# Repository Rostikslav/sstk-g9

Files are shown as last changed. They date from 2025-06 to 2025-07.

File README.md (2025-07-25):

# EcoSwitch

Dieses Repository enthält das Projekt im Rahmen des Moduls **Soft Skills und technische Kompetenz** an der Carl von Ossietzky Universität Oldenburg.

## 📌 Gruppe 9

**Teilnehmer:innen:**
- Vlada Kryvtsova (vlkkvl)
- Emelie Lyhs (LuciaDC245)
- Rostyslav Petrenko (Rostikslav)
- Maximilian Schmidt (DerTafel)
- Zinedin Zerarka (Shuvi12345)

## 📁 Struktur

- `app/` – Android-Applikation
- `embedded/` – Hardware und Mikrocontroller-Firmware
- `docs/` – Projektbezogene Dokumentation

## 📝 Projektbeschreibung
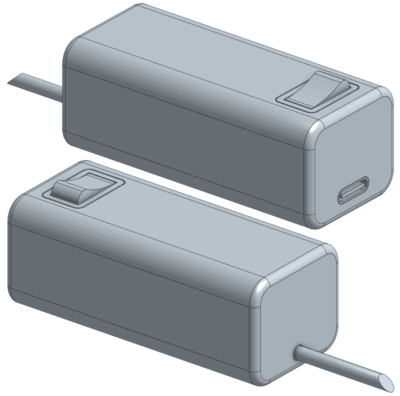
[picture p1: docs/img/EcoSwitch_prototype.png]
EcoSwitch


Ursprünglich war geplant, eine vollwertige, fernsteuerbare Steckdosenleiste zu entwickeln, mit der sich Geräte über WLAN kontrollieren lassen. Diese Idee wurde jedoch aus sicherheitstechnischen Gründen abgelehnt, da sie mit Netzspannung gearbeitet hätte und dadurch ein erhöhtes Risiko bestand.

Stattdessen wurde das Konzept angepasst: Unser aktuelles Projekt, der EcoSwitch, verfolgt dieselben Ziele – nämlich Energieeinsparung und intelligentes Gerätemanagement – aber in Form eines kompakten USB-basierten Adapters. Diese Lösung reduziert das Gefahrenpotenzial erheblich, behält aber alle geplanten Funktionen bei.

Der EcoSwitch ermöglicht:
- Fernsteuerung über eine Android-App (WLAN)
- Timer-gesteuertes Ein-/Ausschalten von angeschlossenen Geräten
- Lokale Steuerung per Taster
- LED-Statusanzeige für den aktuellen Zustand

Das Projekt zielt darauf ab, unnötigen Stromverbrauch zu reduzieren, die Lebensdauer von Geräten zu verlängern und einen kleinen, aber effektiven Beitrag zum Umweltschutz zu leisten.

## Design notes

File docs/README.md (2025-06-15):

## Docs
This directory contains project-related documentation, including planning notes, deadlines, user stories, images and other supporting materials that guide the development process and track progress.

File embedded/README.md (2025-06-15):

## Embedded
Contains all hardware- and firmware-related components of the project, including microcontroller code and circuit schematics.

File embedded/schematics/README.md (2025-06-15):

## Schematics
Includes hardware schematics, wiring diagrams, and other design files that describe the physical circuit setup used in the project.

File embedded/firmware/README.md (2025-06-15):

## Firmware
Stores the source code for the microcontroller (e.g., Arduino/ESP8266). This includes sensor handling, communication logic, and device behavior.

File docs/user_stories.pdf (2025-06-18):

EcoSwitch Projekt | User Stories

Timer-Funktionen

User Story

Als Benutzer möchte ich einen Timer fur meine Ger ¨ | äte einstellen können,
so dass ich Energie sparen und unnötigen Stromverbrauch uber Nacht vermeiden kann. ¨

Akzeptanzkriterien:

- Der Benutzer kann Timer zwischen 1 Minute und 24 Stunden einstellen
- Die Timer-Einstellung erfolgt uber eine intuitive Zeitauswahl (Stunden/Minuten) ¨
- Nach Ablauf des Timers wird das EcoSwitch automatisch ausgeschaltet
- Der Benutzer erhält eine Bestätigung, wenn der Timer erfolgreich gesetzt wurde
- Bei Verbindungsfehlern wird eine Fehlermeldung angezeigt
- Der Timer kann nur bei eingeschaltetem EcoSwitch gestartet werden

User Story

Als Benutzer möchte ich den Timer während des Betriebs anpassen können, so dass ich flexibel auf veränderte Bedurfnisse reagieren kann. ¨

Akzeptanzkriterien:

- Der aktive Timer kann verlängert oder verkurzt werden ¨
- Anderungen werden sofort an das EcoSwitch ¨ | ubertragen ¨
- Der Benutzer kann den Timer komplett stoppen/deaktivieren
- Bei Timer-Anderungen wird die neue Restzeit sofort angezeigt ¨
- Timer können nicht auf negative Werte gesetzt werden
- Eine Bestätigung erscheint bei erfolgreicher Timer-Anpassung

Fernsteuerung & Status

User Story

Als Benutzer möchte ich mein EcoSwitch-Gerät aus der Ferne ein- und ausschalten können,
so dass ich bequem vom Sofa aus Geräte steuern kann, ohne aufstehen zu mussen. ¨

Akzeptanzkriterien:

- Ein-/Ausschalten funktioniert uber einen gut sichtbaren Button in der App ¨
- Die Statusänderung wird innerhalb von 2 Sekunden ubertragen ¨
- Bei Verbindungsproblemen wird eine Fehlermeldung angezeigt

- Die erfolgreiche Verbindung wird durch eine erfolgreiche Meldung angezeigt
- Der physische Notschalter am EcoSwitch hat Vorrang vor App-Befehlen
- Befehle werden nur bei bestehender Verbindung zum EcoSwitch gesendet

User Story

Als Benutzer möchte ich den aktuellen Status meines Geräts (ein/aus/Timer aktiv) auf einen Blick sehen,
so dass ich immer weiß, ob meine Geräte gerade Strom verbrauchen.

Akzeptanzkriterien:

- Der Status wird prominent auf dem Hauptbildschirm angezeigt
- Unterschiedliche Farben fur verschiedene Zust ¨ | ände (Grun=ein, Rot=aus, Orange=Timer) ¨
- Status wird automatisch alle 5 Sekunden aktualisiert
- Status-Icons sind selbsterklärend und entsprechen der Hardware-LED
- Temperaturstatus wird zusätzlich angezeigt (Normal/Warnung/Kritisch)

User Story

Als Benutzer möchte ich eine Live-Anzeige der verbleibenden Timer-Zeit sehen, so dass ich weiß, wann mein Gerät automatisch ausgeschaltet wird.

Akzeptanzkriterien:

- Timer-Countdown wird in Echtzeit (sekundlich) aktualisiert ¨
- Zeit wird im Format “HH:MM:SS” angezeigt
- Bei inaktivem Timer wird “Kein Timer aktiv” angezeigt
- In den letzten 60 Sekunden wird die Anzeige hervorgehoben
- Bei Timer-Ablauf erscheint eine deutliche Benachrichtigung

Sicherheit & Uberwachung ¨

User Story

Als Benutzer möchte ich Temperatur-Warnungen erhalten,
so dass ich rechtzeitig uber ¨ | Uberhitzung informiert werde und Sch ¨ | äden verhindern kann.

Akzeptanzkriterien:

- Warnung bei Temperaturen uber 60 ¨ | °C (konfigurierbar)
- Kritische Warnung bei Temperaturen uber 80 ¨ | °C
- Automatische Abschaltung bei kritischen Temperaturen (uber 85 ¨ | °C)
- Temperatur wird kontinuierlich alle 10 Sekunden uberpr ¨ | uft ¨

Benutzerfreundlichkeit

User Story

Als Benutzer möchte ich eine einfache und intuitive Bedienoberfläche haben, so dass ich die App ohne Einarbeitung sofort nutzen kann.

Akzeptanzkriterien:

- Alle wichtigen Funktionen sind mit maximal 2 Klicks erreichbar
- Buttons haben aussagekräftige Beschriftungen oder universelle Icons
- Die App folgt den Android Material Design Guidelines
- Schriftgrößen sind fur alle Altersgruppen gut lesbar ¨
- Farbkontraste erfullen Accessibility-Standards ¨
- Fehlermeldungen sind verständlich

## Definition of Done (DoD)

Eine User Story gilt als fertig (Done), wenn alle folgenden Kriterien erfullt sind: ¨

Funktionale Kriterien

¥ Alle Akzeptanzkriterien der User Story sind implementiert

¥ Feature funktioniert auf Android 8.0+

¥ WiFi-Verbindung zum EcoSwitch funktioniert stabil

Technische Qualität

¥ Code ist von dem ganzen Team reviewed

¥ Integration Tests fur Hardware-Kommunikation existieren ¨

User Experience

¥ UI folgt Material Design Guidelines 3

¥ App funktioniert im Hoch- und Querformat

¥ Fehlermeldungen sind benutzerfreundlich formuliert

¥ Loading States und Progress Indicators sind implementiert

Sicherheit & Stabilität

¥ Keine sensitive Daten werden im Plain Text gespeichert

¥ App sturzt nicht ab bei Verbindungsfehlern ¨

¥ Timeout-Handling fur alle Netzwerk-Requests ¨

Testing & Dokumentation

¥ Automatisierte UI-Tests fur kritische User Flows ¨

¥ Code ist ausreichend kommentiert

¥ README enthält Build- und Setup-Anweisungen

¥ Known Issues sind dokumentiert

Performance

¥ App-Größe unter 20 MB

¥ Netzwerk-Requests unter 2 Sekunden Response Zeit

¥ UI reagiert flussig (60 FPS, keine ANRs) ¨

¥ Batterieverbauch im normalen Bereich

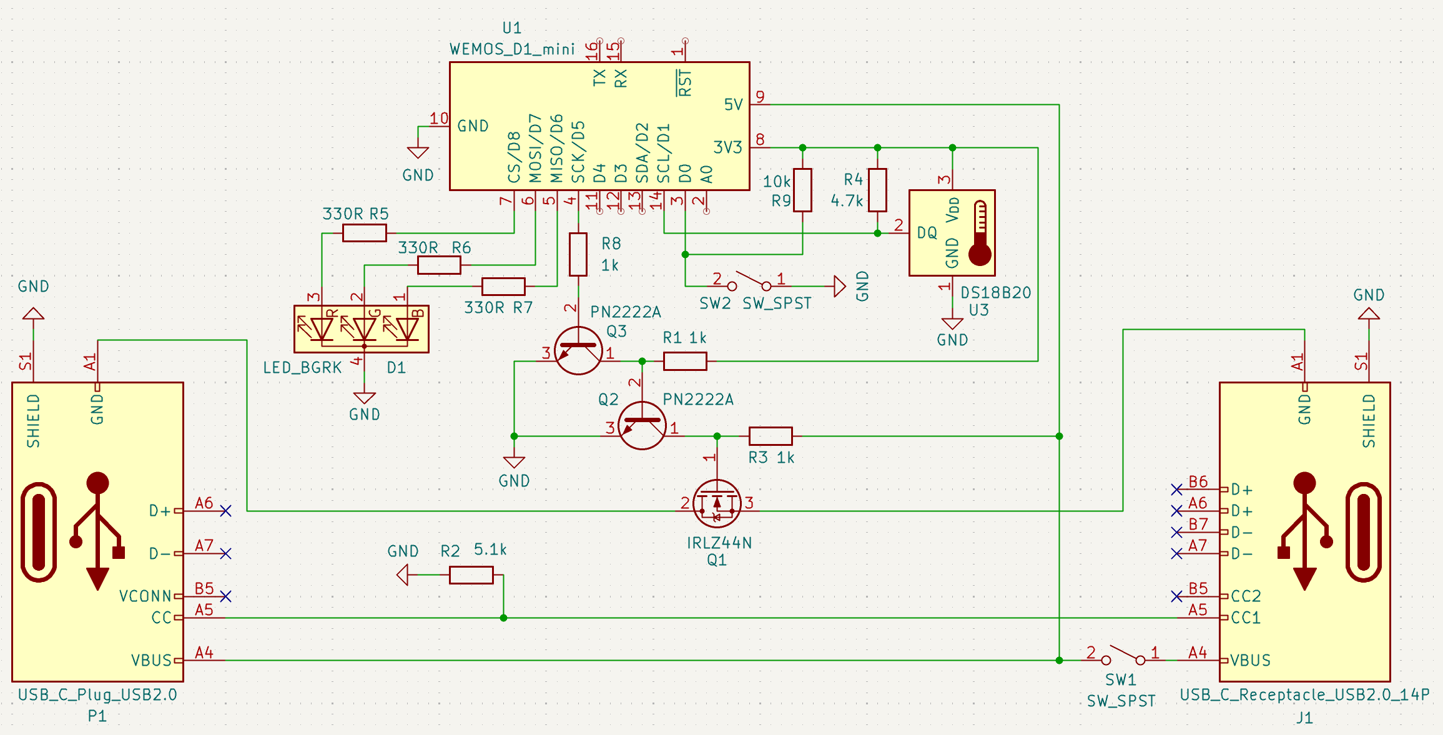
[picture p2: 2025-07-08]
embedded/schematics/schematics_final.png

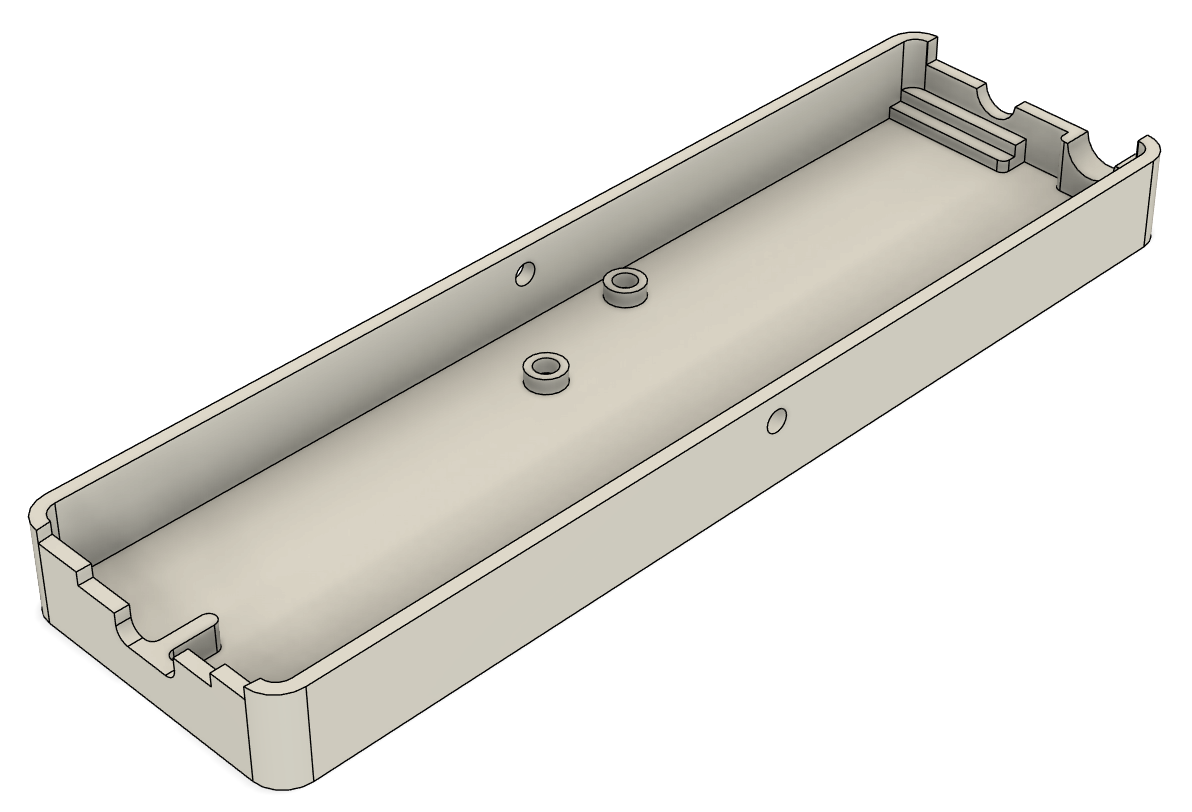
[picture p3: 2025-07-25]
docs/img/final/EcoSwitch_bottom_part_left.png

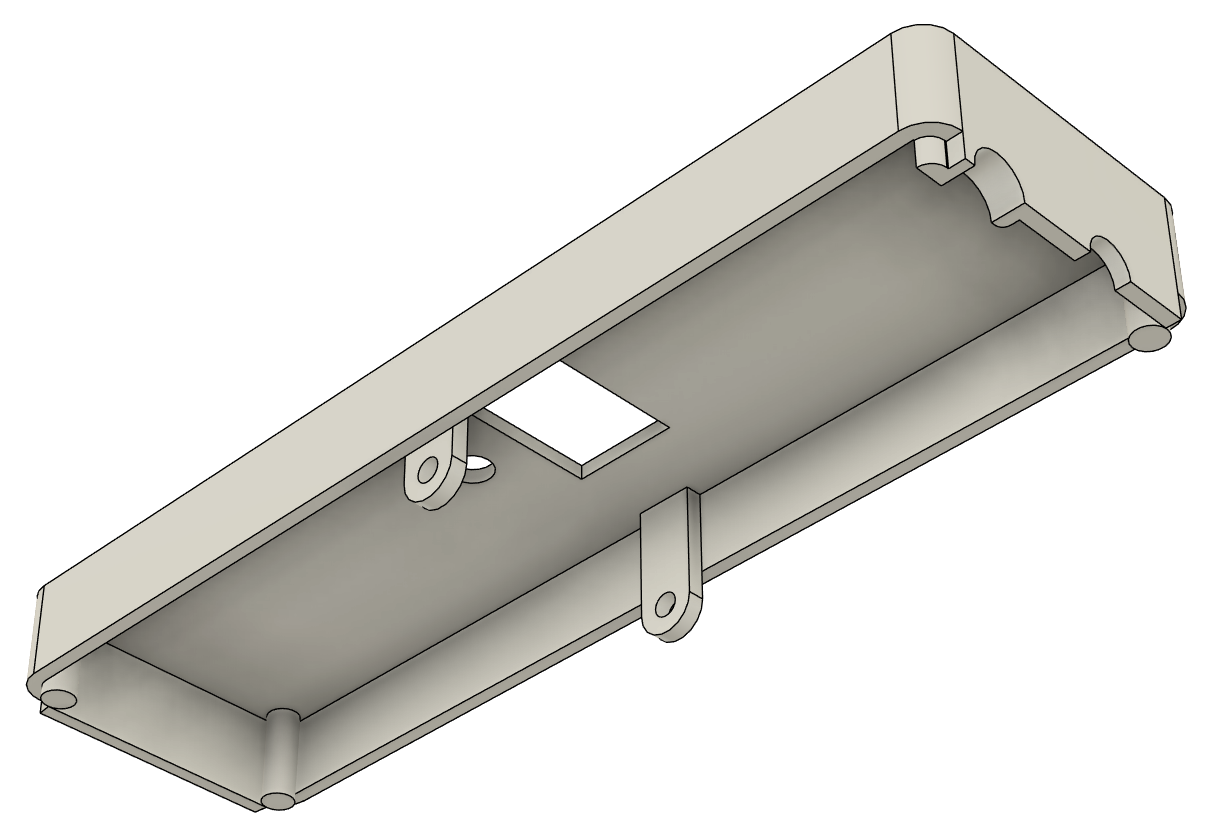
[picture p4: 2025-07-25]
docs/img/final/EcoSwitch_top_part_right.png

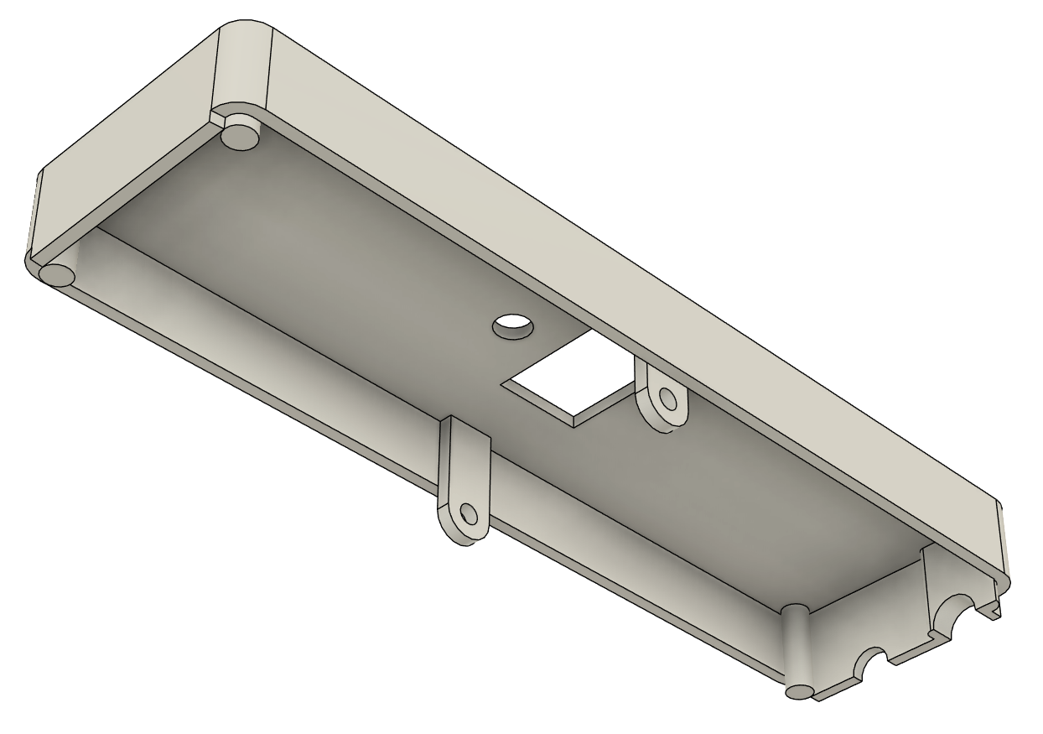
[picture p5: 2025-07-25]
docs/img/final/EcoSwitch_top_part_left.png

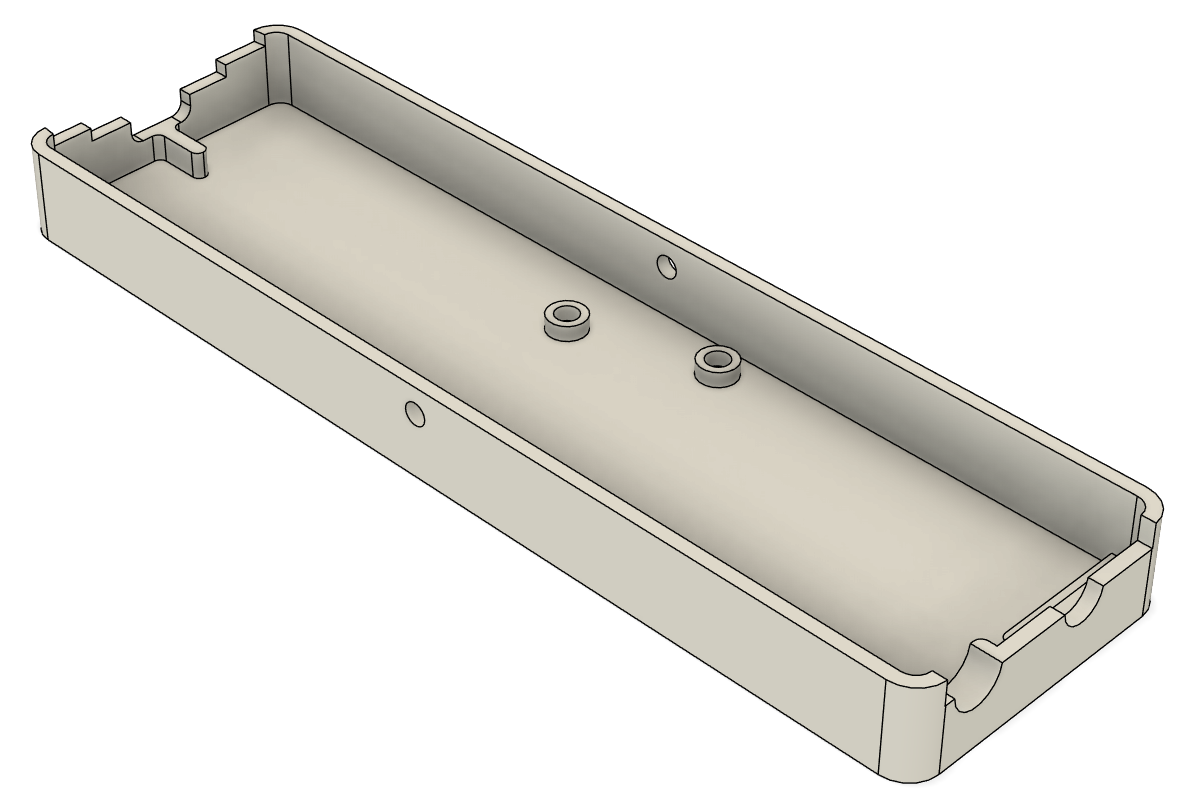
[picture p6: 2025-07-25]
docs/img/final/EcoSwitch_bottom_part_right.png

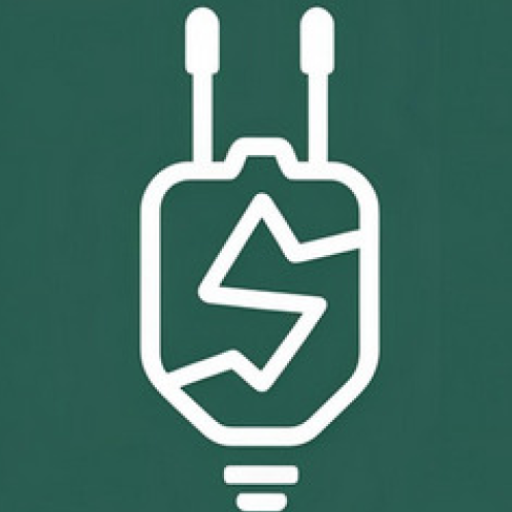
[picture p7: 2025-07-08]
app/src/main/ic_launcher-playstore.png

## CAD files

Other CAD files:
embedded/model/EcoSwitch_final.f3d

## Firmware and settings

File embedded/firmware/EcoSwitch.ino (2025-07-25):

#include <ESP8266WebServer.h>
#include <ESP8266WiFi.h>
#include <WiFiManager.h>
#include <WiFiUdp.h>
#include <EEPROM.h>
#include <Ticker.h>
#include <Wire.h>
#include <Adafruit_BMP085.h>

#include "token.h"
#include "udp.h"

#define SWITCH_PIN D5  // main control pin
#define RESET_PIN D0   // to GND on boot for reset

// indicators
#define BLUE D6
#define RED D7
#define GREEN D8

// UDP
#define BROADCAST_INTERVAL 1000    // 1sec
#define BROADCAST_DURATION 120000  // 2min

// temp sensor
#define TEMP_CUTOFF 50.0
#define TEMP_FAULTY_READING_THRESHOLD 100.0
#define TEMP_READ_INTERVAL 2000  // 2sec
#define COOLDOWN_DURATION 60000  // 1min

ESP8266WebServer server(80);
Ticker blinker;

// udp broadcast
unsigned long broadcastStart = 0;
unsigned long lastBroadcast = 0;
bool enableBroadcast = false;

unsigned long timerEnd = 0;
int timerAction = 0;

Adafruit_BMP085 bmp;
unsigned long temperatureLastRead = 0;
unsigned long cooldownEnd = 0;
bool cooldownMode = false;

// ------ LED ------

void toggle(uint8_t pin) {
    digitalWrite(pin, !digitalRead(pin));
}

void updateLedState() { // based on the switch state
    if (digitalRead(SWITCH_PIN)) {
        digitalWrite(RED, LOW);
        digitalWrite(GREEN, HIGH);
        digitalWrite(BLUE, LOW);
    } else {
        digitalWrite(RED, HIGH);
        digitalWrite(GREEN, LOW);
        digitalWrite(BLUE, LOW);
    }
}

// ------ HANDLERS ------

// validates token
bool auth() {
    if (!server.hasArg("token") || server.arg("token") != String(savedToken)) {
        server.send(403, "text/plain", "Forbidden");
        return false;
    }
    return true;
}

// check the sensor availability
bool checkSensor() {
    if (!bmp.begin()) {
        server.send(500, "text/plain", "Temperature sensor is not detected");
        return false;
    }
    return true;
}

// check whether the server is running
void handlePing() {
    server.send(200, "text/plain", "pong");
}

// initial pairing with token generation
void handleSetup() {
    if (tokenExists()) {
        server.send(403, "text/plain", "Already configured");
        return;
    }

    String token = generateToken(TOKEN_LENGTH);
    saveToken(token);
    enableBroadcast = false;
    updateLedState();
    server.send(200, "text/plain", token);
}

// getter fot the switch state(requires auth)
void handleState() {
    if (!auth())
        return;

    int remainingSeconds = timerEnd ? (timerEnd - millis()) / 1000 : 0;

    String json = "{";
    json += "\"sensorError\":" + String(!bmp.begin() ? "true" : "false") + ",";
    json += "\"state\":" + String(digitalRead(SWITCH_PIN) ? "true" : "false") + ",";
    json += "\"timerEnd\":" + String(remainingSeconds) + ",";
    json += "\"cooldownMode\":" + String(cooldownMode ? "true" : "false");
    json += "}";

    server.send(200, "application/json", json);
}

// setter for the switch state(requires auth)
void handleToggleState() {
    if (!auth() || !checkSensor())
        return;

    if (!server.hasArg("state")) {
        server.send(400, "text/plain", "Missing 'state' parameter");
        return;
    }

    String state = server.arg("state");
    if (state == "1") {
        if (cooldownMode) {
            server.send(409, "text/plain", "Device is in cooldown mode");
            return;
        }
        digitalWrite(SWITCH_PIN, HIGH);
        server.send(200, "text/plain", "ON");
    } else if (state == "0") { // allow turning off even in cooldown mode
        digitalWrite(SWITCH_PIN, LOW);
        server.send(200, "text/plain", "OFF");
    } else {
        server.send(400, "text/plain", "Invalid state. Use 1 or 0.");
    }

    updateLedState();
}

// set/reset timer
void handleTimer() {
    if (!auth() || !checkSensor())
        return;

    if (cooldownMode) {
        server.send(409, "text/plain", "Device is in cooldown mode");
        return;
    }

    if (!server.hasArg("seconds")) {
        server.send(400, "text/plain", "Missing 'seconds' parameter");
        return;
    }

    String rawSeconds = server.arg("seconds");
    int seconds = rawSeconds.toInt();
    bool isValid = rawSeconds.length() > 0 && seconds != 0;

    if (!isValid && rawSeconds != "0") {
        server.send(400, "text/plain", "Invalid parameter 'seconds'. The Value should be an integer.");
        return;
    }

    if (seconds == 0) {
        timerEnd = 0;
        server.send(200, "text/plain", "Timer deactivated.");
        return;
    }

    if (!server.hasArg("action")) {
        server.send(400, "text/plain", "Missing 'action' parameter");
        return;
    }

    String rawAction = server.arg("action");
    if (rawAction != "1" && rawAction != "0") {
        server.send(400, "text/plain", "Invalid parameter 'action'. Use 1 or 0.");
        return;
    }

    timerEnd = millis() + (unsigned long)seconds * 1000;
    timerAction = rawAction.toInt();
    server.send(200, "text/plain", "Timer set.");
}

// getter fot the temperature readings(requires auth)
void handleTemperature() {
    if (!auth() || !checkSensor())
        return;

    float temp = bmp.readTemperature();
    if (isnan(temp) || temp > TEMP_FAULTY_READING_THRESHOLD) {
        server.send(500, "text/plain", "Faulty sensor readings");
    } else {
        server.send(200, "text/plain", String(temp, 1));
    }
}

// forget connected device and reboot
void handleDisconnect() {
    if (!auth())
        return;

    clearToken();
    server.send(200, "text/plain", "Successfully disconnected");
    delay(1000);
    ESP.restart();
}

void setup() {
    pinMode(SWITCH_PIN, OUTPUT);
    pinMode(RESET_PIN, INPUT);

    pinMode(RED, OUTPUT);
    pinMode(GREEN, OUTPUT);
    pinMode(BLUE, OUTPUT);

    digitalWrite(SWITCH_PIN, LOW);
    digitalWrite(RED, LOW);
    digitalWrite(GREEN, LOW);
    digitalWrite(BLUE, LOW);

    Serial.begin(115200);
    Serial.print('\n');

    while (!bmp.begin()) { // blink red if couldn't connect to the sensor
        toggle(RED);
        delay(300);
    }
    digitalWrite(RED, LOW);

    blinker.attach(0.3, []() { // blink blue while in setup mode
        toggle(BLUE);
    });

    randomSeed(micros());
    EEPROM.begin(TOKEN_LENGTH);

    WiFiManager wm;
    if (digitalRead(RESET_PIN) == 0) { // if reset held on boot
        Serial.println("Resetting WiFi and token...");
        wm.resetSettings(); // forget network
        clearToken(); // forget paired device
        ESP.restart();
    } else {
        Serial.println("No reset");
    }

    if (!wm.autoConnect("EcoSwitch-Setup")) // try to auto-connect or open hotspot
        ESP.restart();

    loadToken();
    if (!tokenExists()) {  // only start broadcasting if no token saved
        enableBroadcast = true;
        broadcastStart = millis();
        digitalWrite(BLUE, HIGH);
    } else {
        updateLedState();
    }

    blinker.detach();
    udp.begin(UDP_PORT); // udp setup

    // server handlers
    server.on("/ping", handlePing);
    server.on("/setup", handleSetup);
    server.on("/status", handleState);
    server.on("/temperature", handleTemperature);
    server.on("/toggle", handleToggleState);
    server.on("/timer", handleTimer);
    server.on("/disconnect", handleDisconnect);
    server.begin();
}

void loop() {
    server.handleClient();
    if (!bmp.begin()) { // if sensor failure detected
        digitalWrite(SWITCH_PIN, LOW); // turn off the switch
        updateLedState();
        while (!bmp.begin()) { // while sensor offline
            server.handleClient(); // do not block incoming requests
            toggle(RED); // blink red
            delay(300);
        }
        updateLedState();
    }

    // udp broadcast condition
    if (enableBroadcast && millis() - broadcastStart < BROADCAST_DURATION && millis() - lastBroadcast > BROADCAST_INTERVAL) {
        sendIPBroadcast();
        lastBroadcast = millis();
    }

    // timer state condition
    if (timerEnd && timerEnd < millis()) {
        timerEnd = 0;
        digitalWrite(SWITCH_PIN, timerAction ? HIGH : LOW);
        updateLedState();
    }

    // temperature reading condition
    if (millis() - temperatureLastRead > TEMP_READ_INTERVAL) {
        temperatureLastRead = millis();
        if (!bmp.begin())
            return;
        float t = bmp.readTemperature();
        Serial.println(t);

        if (!isnan(t) && t >= TEMP_CUTOFF) { // if temperature too high
            digitalWrite(SWITCH_PIN, LOW); // cut the power
            updateLedState();
            cooldownMode = true; // enter cooldown mode
            timerEnd = 0; // deactivate timer
            cooldownEnd = millis() + COOLDOWN_DURATION; // set cooldown end time
        }
    }

    // cooldown exit condition
    if (cooldownEnd && millis() > cooldownEnd) {
        cooldownEnd = 0;
        cooldownMode = false;
    }
}

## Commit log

2025-06-18 add core system: - Wi-Fi connection - request auth - UDP discovery - direct switch control - delayed switch control (timer) - temp check
2025-06-21 replace temperature sensor and fix bugs
    [EcoSwitch.ino]
2025-06-22 CONNECTION: now is possible to establish connection to ecoswitch, stop connection process, turn eco switch off and on, and disconnect from it. Another needed bug fixes/improvements: - when eco switch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
2025-06-23 App Logo, Timer Design
2025-06-24 timer test, konnte design und logik leider nicht aufteilen
2025-07-07 TIMER: - hardware timer sync with ui timer - toggle updates with PROCESSING... display - timer updates every 3 sec
2025-07-08 Add files via upload
    Eco swtich case prototype
2025-07-08 added final housing model and corrected schematics
    [EcoSwitch_final.f3d]
